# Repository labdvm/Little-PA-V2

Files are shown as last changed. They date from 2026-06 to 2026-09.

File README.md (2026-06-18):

# Little-PA-V2
Same as Little PA with few improvements

# Order from here:
- <a href="https://www.pcbway.com/project/shareproject/Little_PA_V2_SX1255_HAT_2c8ffceb.html">PCB from PCBWay</a>

# Changes to this version:
- Added island around TCXO and under to isolate heating from the cooper for better temperature stability.
- Added few bigger vias for better ventilation.
- Added Bandpass filter to the TX for better RF isolation.
- Added bridge in case if used without PA, you can jump with two 0R resistors to get signal directly from the SX1255.
- -----------------------------------------------------
# Work with PA:
- R29 and R32 not soldered.
# Work without the PA:
- U4 and C28 not soldered, R29 and R32 soldered.

# Z32IT

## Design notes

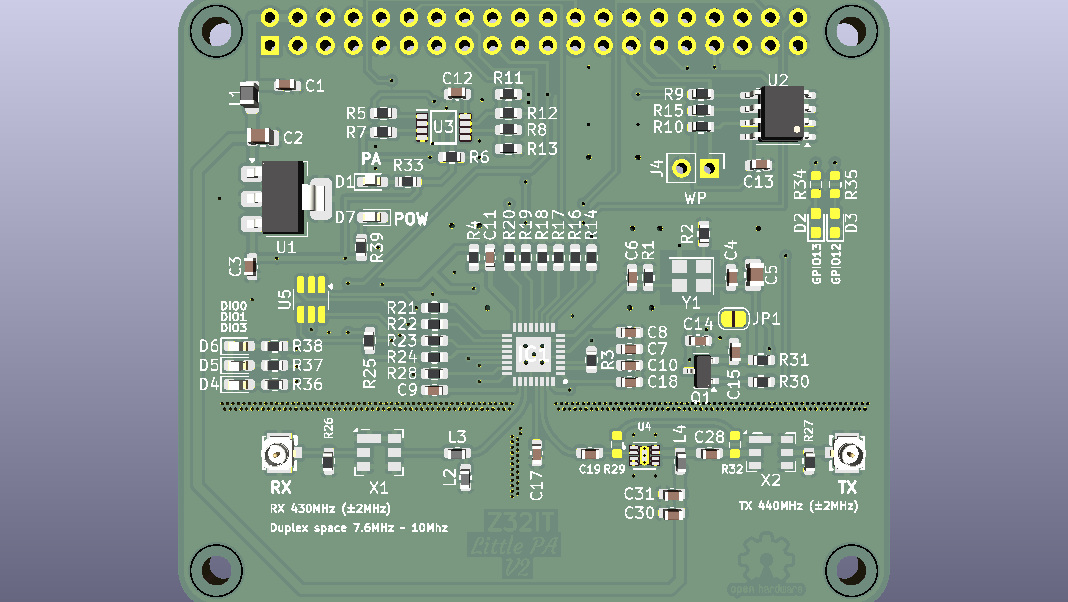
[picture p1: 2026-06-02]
Little PA V2.png

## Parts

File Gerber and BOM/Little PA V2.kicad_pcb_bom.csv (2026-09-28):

Designator | Quantity | Value | Footprint | Package | MPN | DNP | Mount_Type | Manufacturer | Manufacturer Product Number | KiLib_Generator | Description | Sim.Pin | Height | PN | PROD_ID | Part Number | MANUFACTURER_NAME | MF | MOUSER_PRICE-STOCK | DESCRIPTION | MOUSER_PART_NUMBER | Price | Check_prices | HEIGHT | SnapEDA_Link | MP | Description_1 | Availability | MANUFACTURER_PART_NUMBER | MAXIMUM_PACKAGE_HEIGHT | STANDARD | PARTREV | Purchase-URL | MANUFACTURER | Aliexpress | Model | TCXO-Footprints
C1, C10, C11, C15, C3, C30 | 6 | 1u | C_0603_1608Metric |  |  |  | smt | YAGEO | CC0603JRX7R6BB105
C12, C13, C14, C4, C7, C8, C9 | 7 | 100n | C_0603_1608Metric |  |  |  | smt | Vishay Vitramon | VJ0603Y104JXQPW1BC
C17, C19, C28, C31 | 4 | 100p | C_0603_1608Metric |  |  |  | smt | KEMET | C0603C101J8GACTU
C18 | 1 | 10n | C_0603_1608Metric |  |  |  | smt | KEMET | C0603C103K8RACTU
C2, C5 | 2 | 22u | C_0805_2012Metric |  | 1276-3148-1-ND |  | smt | Samsung Electro-Mechanics | CL31B226MPHNNNE | SMD_2terminal_chip_molded
C6 | 1 | 10p | C_0603_1608Metric |  |  |  | smt | KEMET | C0603C100J8GACTU
D1 | 1 | Red | LED_0603_1608Metric_Pad1.05x0.95mm_HandSolder |  | 160-1479-1-ND |  | smt | Lite-On Inc. | LTST-S270KRKT |  | Light emitting diode, small symbol | 1=K 2=A
D4, D5, D6 | 3 | Yellow | LED_0603_1608Metric_Pad1.05x0.95mm_HandSolder |  | 160-1437-1-ND |  | smt | Lite-On Inc. | LTST-C190KSKT |  | Light emitting diode, small symbol | 1=K 2=A
D7 | 1 | White | LED_0603_1608Metric_Pad1.05x0.95mm_HandSolder |  | 160-LTST-T180UWETCT-ND |  | smt | Lite-On Inc. | LTST-T180UWET |  | Light emitting diode, small symbol | 1=K 2=A
IC1 | 1 | SX1255 | QFN50P500X500X80-33N-D |  | SX1255IWLTRT |  | smt | Semtech Corporation | SX1255IWLTRT |  |  |  | 0.8 | 947-SX1255IWLTRT
J1, J2 | 2 | U.FL | U.FL |  | 343-CONMHF1-SMD-G-TCT-ND |  | smt | TE Connectivity Linx | CONMHF1-SMD-G-T |  |  |  |  |  | CONN-09193
L1 | 1 | 600 ohm/100MHz | L_0805_2012Metric |  | 490-1046-1-ND |  | smt | Murata Electronics | BLM21BD601SN1D |  | FERRITE BEAD 600 OHM 0805 1LN
L2 | 1 | 82n | L_0603_1608Metric |  |  |  | smt | Johanson Technology Inc. | LRC0603CJ82NGV001T
L3 | 1 | 39n | L_0603_1608Metric |  |  |  | smt | Johanson Technology Inc. | LRC0603CJ39NGV001T
L4 | 1 | 68nH | L_0603_1608Metric |  |  |  | smt | Johanson Technology Inc. | LRC0603CJ68NGV001T |  |  |  |  |  |  | 712-LRC0603CJ68NGV001TCT-ND
Q1 | 1 | BSS84 | SOT-23 |  | 3372-BSS84TR-ND |  | smt | MDD | BSS84
R1, R25 | 2 | 10K | R_0603_1608Metric |  |  |  | smt | Vishay Dale | CRCW060310K0FKEA
R10 | 1 | 1K | R_0603_1608Metric |  |  |  | smt | Vishay Dale | CRCW06031K00FKEA
R11, R13, R26, R27 | 4 | 1M | R_0603_1608Metric |  |  |  | smt | Vishay Dale | CRCW06031M00FKEA
R12, R17, R18, R19, R21, R23, R24, R30, R5, R6, R8 | 11 | 330R | R_0603_1608Metric |  |  |  | smt | Vishay Dale | CRCW0603330RFKEA
R14, R16, R20, R22, R28 | 5 | 33R | R_0603_1608Metric |  |  |  | smt | Vishay Dale | CRCW060333R0FKEA
R15, R38, R39, R9 | 4 | 3K3 | R_0603_1608Metric |  |  |  | smt | Vishay Dale | CRCW06033K30FKEA
R2, R7 | 2 | 0R | R_0603_1608Metric |  |  |  | smt | Vishay Dale | CRCW06030000Z0EA
R3, R31, R4 | 3 | 1R | R_0603_1608Metric |  |  |  | smt | Vishay Dale | CRCW06031R00FKEA
R33, R36, R37 | 3 | 1K5 | R_0603_1608Metric |  |  |  | smt | Vishay Dale | CRCW06031K50JNEA
U1 | 1 | MCP1703Ax-330xxDB | SOT-223-3_TabPin2 |  | MCP1703T-3302E/DBCT-ND |  | smt | Microchip Technology | MCP1703T-3302E/DB
U2 | 1 | 24LC256 | SOIC-8_3.9x4.9mm_P1.27mm |  | 24LC256-I/SN-ND |  | smt | Microchip Technology | 24LC256-I/SN
U3 | 1 | 74LVC1G74DP_125 | SOP65P400X110-8N | TSSOP8-8 Nexperia USA Inc. | 1727-5983-1-ND |  | smt | Nexperia USA Inc. | 74LVC1G74DP,125 |  |  |  |  |  |  |  | Nexperia | NXP USA Inc. | https://www.mouser.co.uk/ProductDetail/Nexperia/74LVC1G74DP125?qs=me8TqzrmIYWtKZiCsFqsMg%3D%3D | 74LVC1G74 - Single D-type flip-flop with set and reset; positive edge trigger@en-us | 771-LVC1GDP125 | None | https://www.snapeda.com/parts/74LVC1G74DP,125/NXP+Semiconductors/view-part/?ref=eda | 1.1mm | https://www.snapeda.com/parts/74LVC1G74DP,125/NXP+Semiconductors/view-part/?ref=snap | 74LVC1G74DP,125 | Flip Flop 1 Element D-Type 1 Bit Positive Edge 8-TSSOP, 8-MSOP (0.118, 3.00mm Width) | In Stock | 74LVC1G74DP,125
U4 | 1 | TQP3M9036 | SON50P200X200X95-9N | DFN-8 Qorvo | 2312-TQP3M9036CT-ND |  | smt | Qorvo | TQP3M9036 |  |  |  |  |  |  |  |  | Qorvo |  |  |  | None | https://www.snapeda.com/parts/TQP3M9036/Qorvo/view-part/?ref=eda |  | https://www.snapeda.com/parts/TQP3M9036/Qorvo/view-part/?ref=snap | TQP3M9036 | RF Amp Chip Single GP 2GHz 5.25V 8-Pin DFN EP T/R | In Stock |  | 0.95mm | IPC-7351B | N/A | https://www.snapeda.com/api/url_track_click_mouser/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 | Qorvo
X1 | 1 | TA0655A | Filter_SAW-6_3.8x3.8mm |  |  |  | smt |  |  |  | Bandpass Filter, 430MHz, BW-4MHz |  |  |  |  |  |  |  |  |  |  |  |  |  |  |  |  |  |  |  |  |  |  |  | https://www.aliexpress.com/item/1005011831789075.html?sourceType=1
X2 | 1 | TA2490A | Filter_SAW_Epcos_DCC6C_3x3mm |  |  |  | smt |  |  |  | Bandpass Filter, 440MHz, BW-2MHz |  |  |  |  |  |  |  |  |  |  |  |  |  |  |  |  |  |  |  |  |  |  |  | https://www.aliexpress.com/item/1005011831747244.html?sourceType=1
Y1 | 1 | 38.4MHz | Crystal_SMD_3225-4Pin_3.2x2.5mm |  | 114-TG2520SMN38.4000M-MCGNNM3CT-ND |  | smt | EPSON | TG2520SMN 38.4000M-MCGNNM3 |  | Clipped SW/0.5~1ppm |  |  |  |  |  |  |  |  |  |  |  |  |  |  |  |  |  |  |  |  |  |  |  |  | KDS-DSB321SDN or other brands | 3225 or 2510

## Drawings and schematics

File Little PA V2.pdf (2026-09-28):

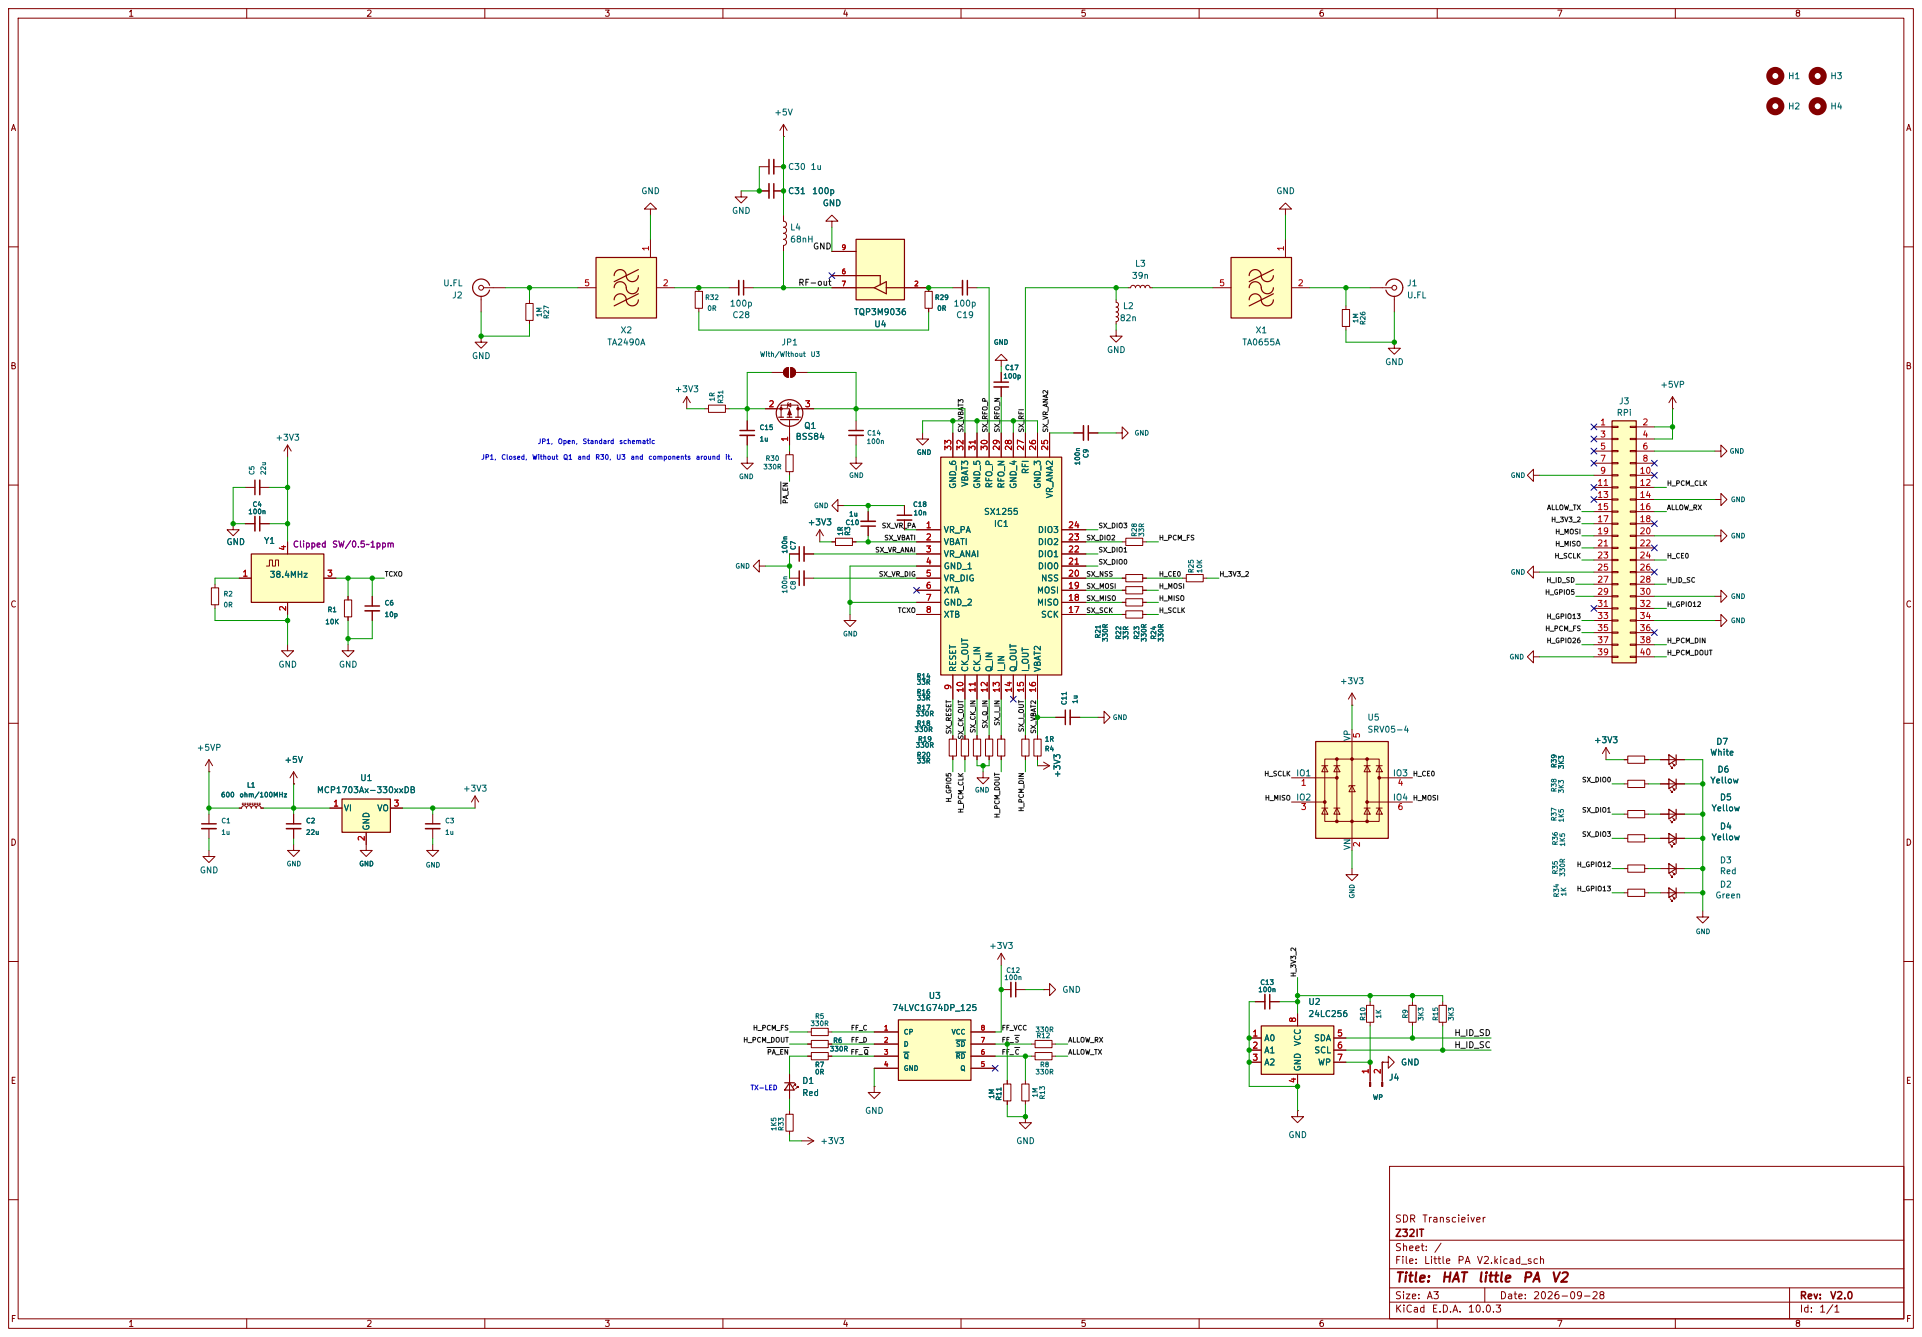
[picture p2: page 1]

JP1, Closed, Without Q1 and R30, U3 and components around it.

SDR Transcieiver
Sheet: /
File: Little PA V2.kicad_sch
Title: HAT little PA V2

Size: A3 | Rev: V2.0 | F Date: 2026-09-28
KiCad E.D.A. 10.0.3 | Id: 1/1

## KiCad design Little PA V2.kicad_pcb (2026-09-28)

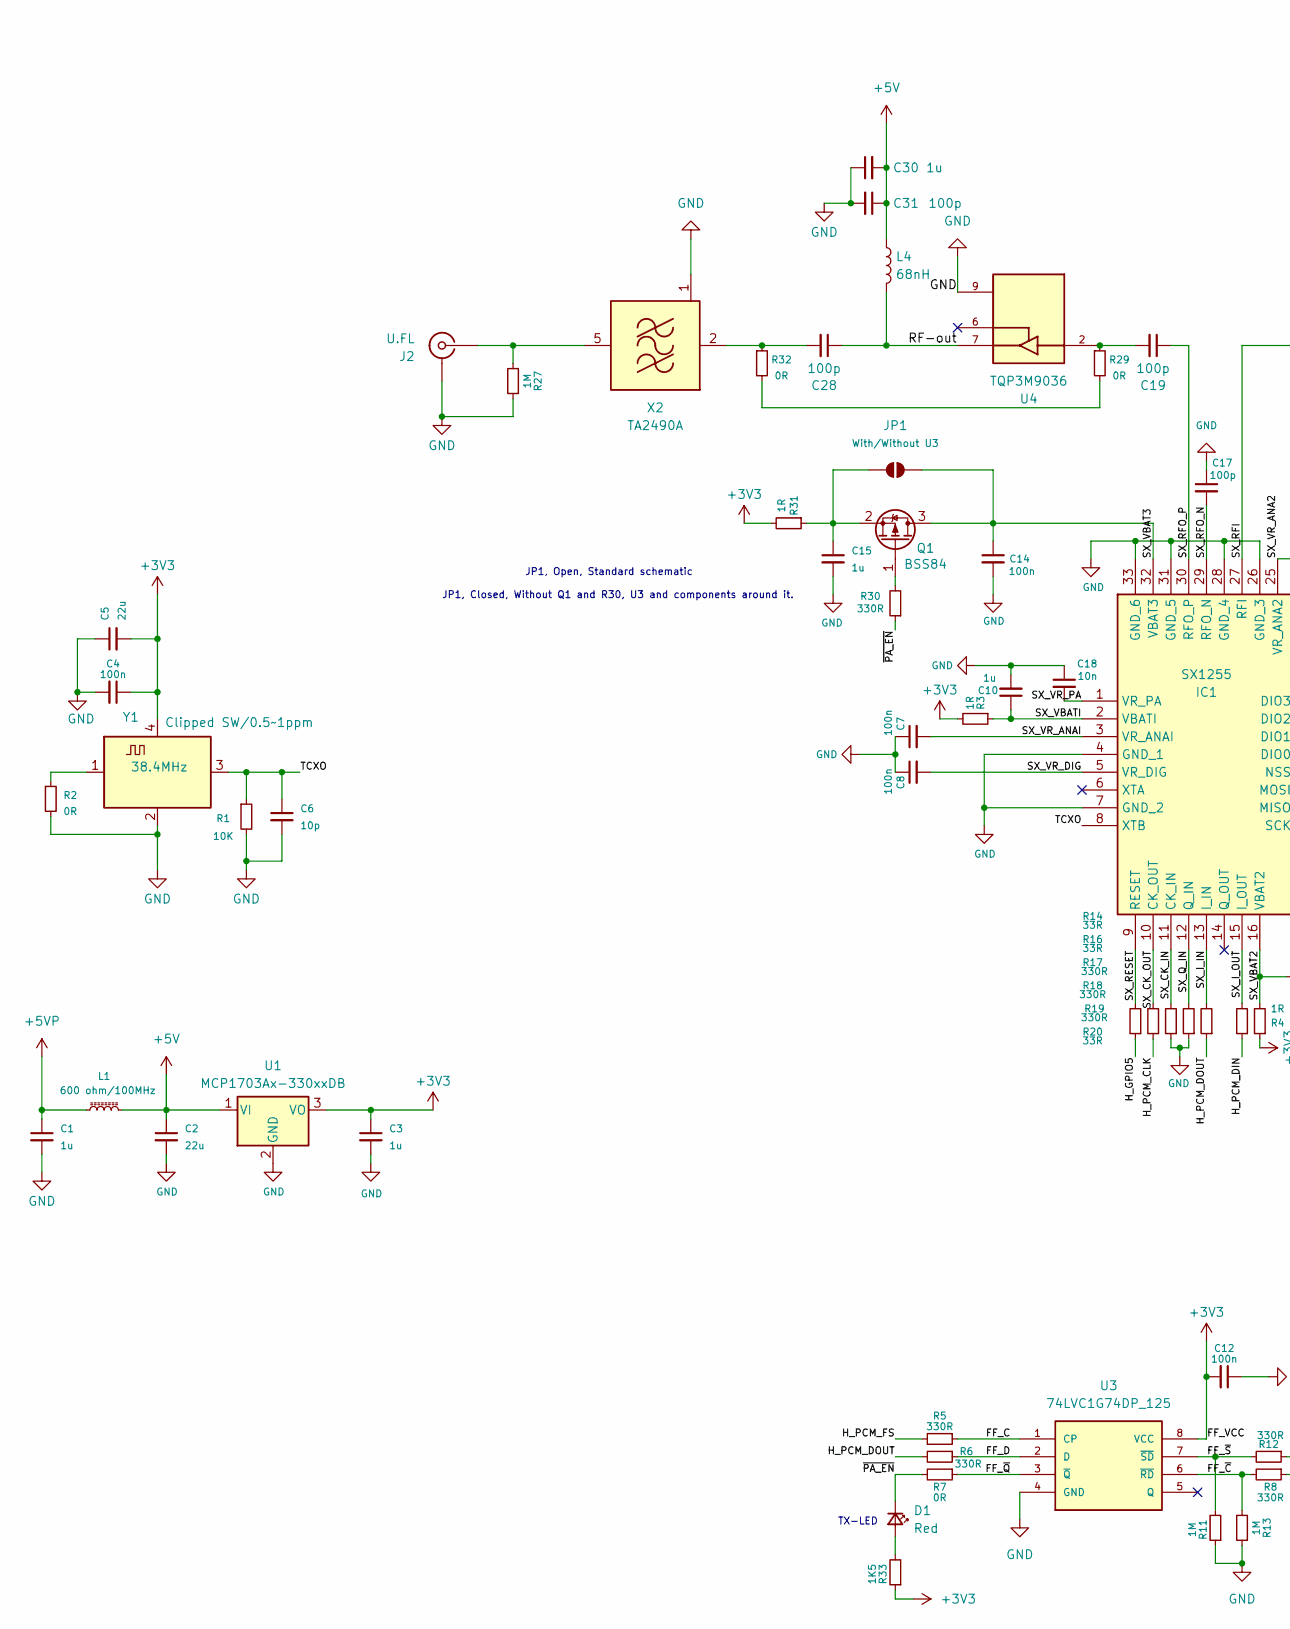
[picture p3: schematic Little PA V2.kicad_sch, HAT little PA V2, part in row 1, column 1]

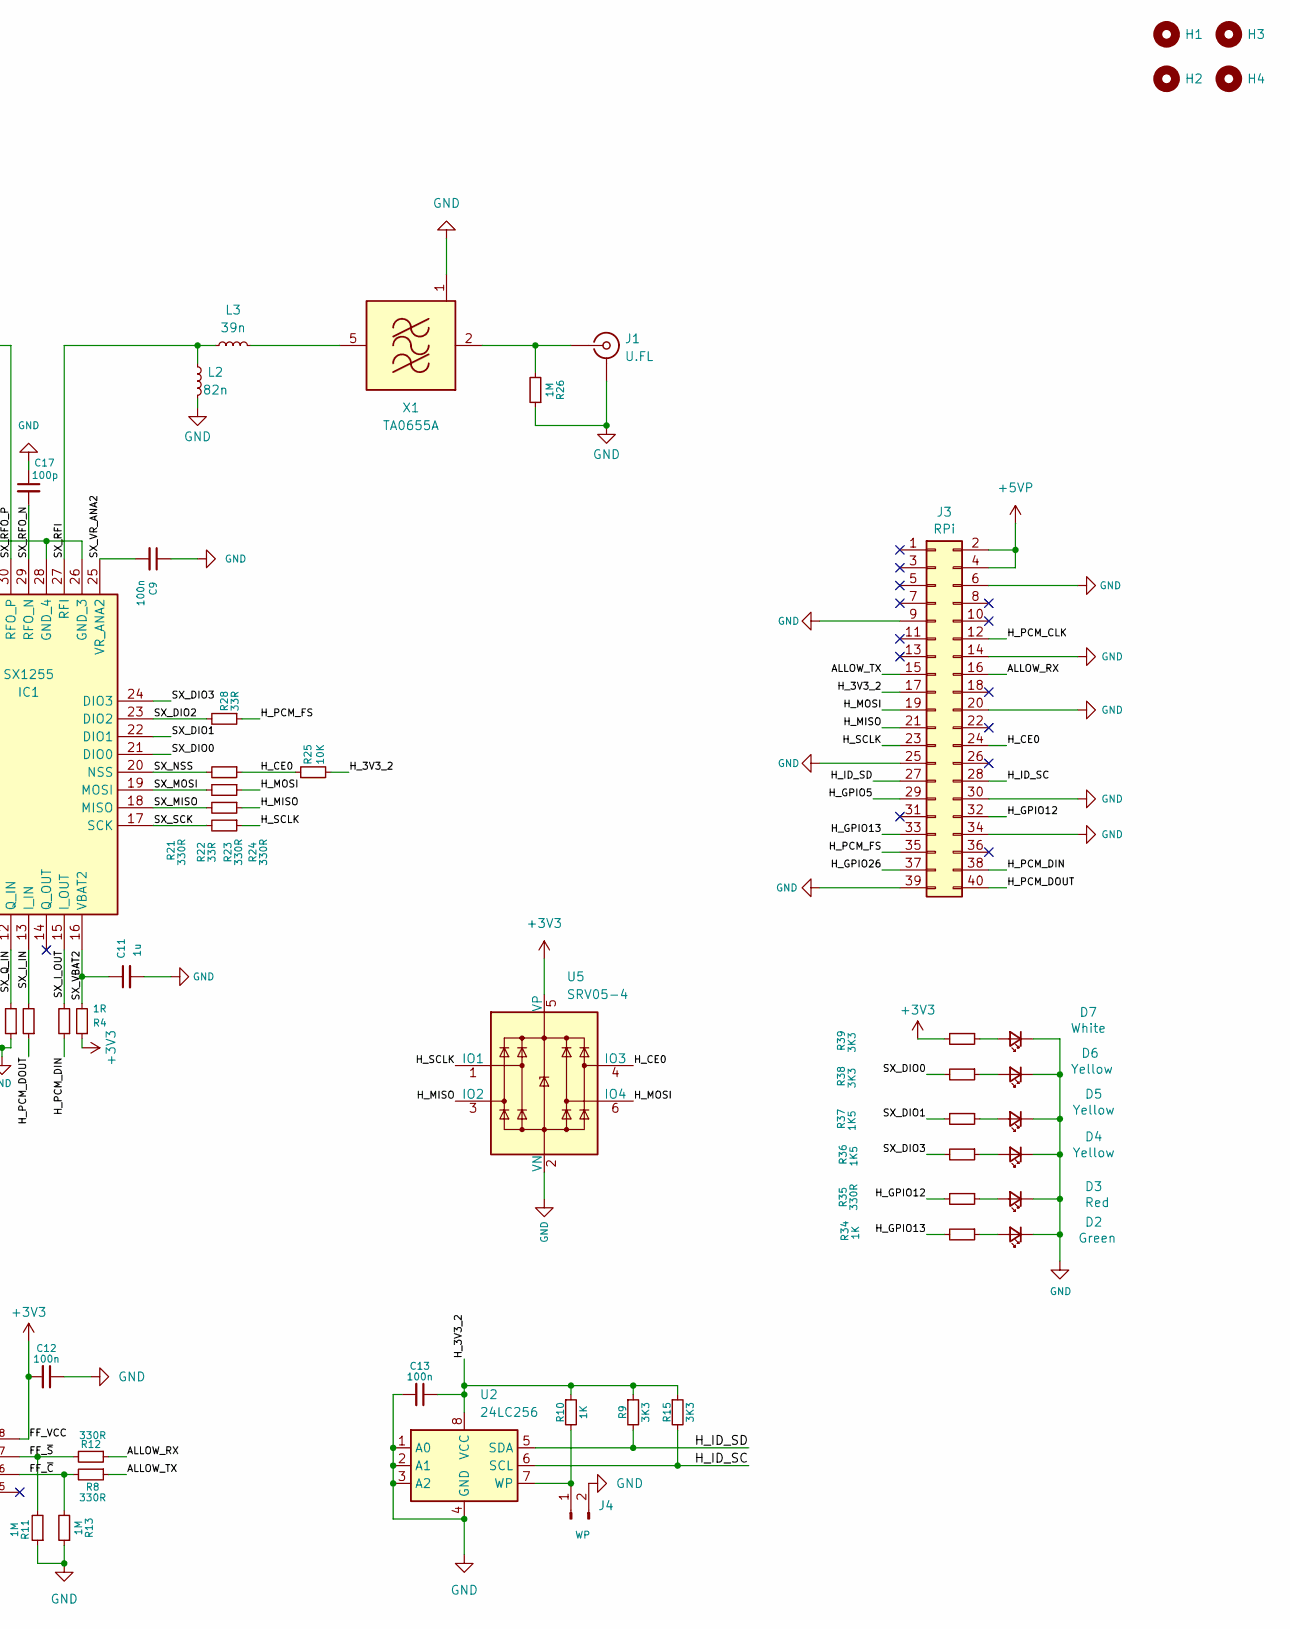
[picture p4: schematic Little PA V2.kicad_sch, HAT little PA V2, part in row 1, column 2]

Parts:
C1, C3, C10, C11, C15, C30: 1u; C_0603_1608Metric; Part Number 311-3484-1-ND
C2, C5: 22u; C_0805_2012Metric; Part Number 1276-3148-1-ND
C4, C7, C8, C9, C12, C13, C14: 100n; C_0603_1608Metric; Part Number 720-1688-1-ND
C6: 10p; C_0603_1608Metric; Part Number 399-14932-1-ND
C17, C19, C28, C31: 100p; C_0603_1608Metric; Part Number 399-15348-1-ND
C18: 10n; C_0603_1608Metric; Part Number 399-C0603C103K8RACTUCT-ND
D1, D3: Red; LED_0603_1608Metric_Pad1.05x0.95mm_HandSolder; Part Number 160-1479-1-ND
D2: Green; LED_0603_1608Metric_Pad1.05x0.95mm_HandSolder; Part Number 754-APT1608SGD3CT-ND
D4, D5, D6: Yellow; LED_0603_1608Metric_Pad1.05x0.95mm_HandSolder; Part Number 160-1437-1-ND
D7: White; LED_0603_1608Metric_Pad1.05x0.95mm_HandSolder; Part Number 160-LTST-T180UWETCT-ND
H1, H2, H3, H4: MountingHole; MountingHole_2.7mm_M2.5_DIN965
IC1: SX1255; QFN50P500X500X80-33N-D; Part Number SX1255IWLTRTCT-ND
J1, J2: U.FL; Part Number 343-CONMHF1-SMD-G-TCT-ND
J3: RPi; PinSocket_2x20_P2.54mm_Vertical
J4: WP; PinHeader_1x02_P2.54mm_Vertical
JP1: With/Without U3; SolderJumper-2_P1.3mm_Open_RoundedPad1.0x1.5mm
L1: 600 ohm/100MHz; L_0805_2012Metric; Part Number 490-1046-1-ND
L2: 82n; L_0603_1608Metric; Part Number 712-LRC0603CJ82NGV001TCT-ND
L3: 39n; L_0603_1608Metric; Part Number 712-LRC0603CJ39NGV001TCT-ND
L4: 68nH; L_0603_1608Metric; Part Number 712-LRC0603CJ68NGV001TCT-ND
Q1: BSS84; SOT-23; Part Number 3372-BSS84TR-ND
R1, R25: 10K; R_0603_1608Metric; Part Number 541-10.0KHCT-ND
R2, R7, R29, R32: 0R; R_0603_1608Metric; Part Number 541-0.0GCT-ND
R3, R4, R31: 1R; R_0603_1608Metric; Part Number 541-1.00HHCT-ND
R5, R6, R8, R12, R17, R18, R19, R21, R23, R24, R30, R35: 330R; R_0603_1608Metric; Part Number 541-330HCT-ND
R9, R15, R38, R39: 3K3; R_0603_1608Metric; Part Number 541-3.30KHCT-ND
R10, R34: 1K; R_0603_1608Metric; Part Number 541-1.00KHCT-ND
R11, R13, R26, R27: 1M; R_0603_1608Metric; Part Number 541-1.00MHCT-ND
R14, R16, R20, R22, R28: 33R; R_0603_1608Metric; Part Number 541-33.0HCT-ND
R33, R36, R37: 1K5; R_0603_1608Metric; Part Number 541-1.5KGCT-ND
U1: MCP1703Ax-330xxDB; SOT-223-3_TabPin2; Part Number MCP1703T-3302E/DBCT-ND
U2: 24LC256; SOIC-8_3.9x4.9mm_P1.27mm; Part Number 24LC256-I/SN-ND
U3: 74LVC1G74DP_125; SOP65P400X110-8N; Part Number 1727-5983-1-ND
U4: TQP3M9036; SON50P200X200X95-9N; Part Number 2312-TQP3M9036CT-ND
U5: SRV05-4; SOT-23-6_Handsoldering; DigiKey Part Number SRV05-4CT-ND
X1: TA0655A; Filter_SAW-6_3.8x3.8mm
X2: TA2490A; Filter_SAW_Epcos_DCC6C_3x3mm
Y1: 38.4MHz; Crystal_SMD_3225-4Pin_3.2x2.5mm; Part Number 114-TG2520SMN38.4000M-MCGNNM3CT-ND

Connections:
+3V3: C3.1, C4.1, C5.2, C12.2, R3.2, R4.1, R31.2, R33.1, R39.2, U1.3 (VO), U3.8 (VCC), U5.5 (VP), Y1.4 (VDD)
+5V: C2.1, C30.2, C31.1, L1.2, L4.1, U1.1 (VI)
+5VP: C1.1, J3.2, J3.4, L1.1
/ALLOW_RX: J3.16, R12.1
/ALLOW_TX: J3.15, R8.1
/FF_C: R5.1, U3.1 (CP)
/FF_D: R6.1, U3.2 (D)
/FF_~C: R8.2, R13.2, U3.6 (~RD)
/FF_~Q: R7.1, U3.3 (~Q)
/FF_~S: R11.2, R12.2, U3.7 (~SD)
/H_3V3_2: C13.1, J3.17, R9.1, R10.1, R15.1, R25.2, U2.8 (VCC)
/H_CE0: J3.24, R24.1, R25.1, U5.4 (IO3)
/H_GPIO5: J3.29, R14.1
/H_GPIO12: J3.32, R35.2
/H_GPIO13: J3.33, R34.2
/H_GPIO26: J3.37
/H_ID_SC: J3.28, R15.2, U2.6 (SCL)
/H_ID_SD: J3.27, R9.2, U2.5 (SDA)
/H_MISO: J3.21, R22.1, U5.3 (IO2)
/H_MOSI: J3.19, R23.1, U5.6 (IO4)
/H_PCM_CLK: J3.12, R16.1
/H_PCM_DIN: J3.38, R20.1
/H_PCM_DOUT: J3.40, R6.2, R19.1
/H_PCM_FS: J3.35, R5.2, R28.1
/H_SCLK: J3.23, R21.1, U5.1 (IO1)
/RF-out: C28.1, L4.2, U4.7
/SX_CK_IN: IC1.11 (CK_IN), R17.2
/SX_CK_OUT: IC1.10 (CK_OUT), R16.2
/SX_DIO0: IC1.21 (DIO0), R38.2
/SX_DIO1: IC1.22 (DIO1), R37.2
/SX_DIO2: IC1.23 (DIO2), R28.2
/SX_DIO3: IC1.24 (DIO3), R36.2
/SX_I_IN: IC1.13 (I_IN), R19.2
/SX_I_OUT: IC1.15 (I_OUT), R20.2
/SX_MISO: IC1.18 (MISO), R22.2
/SX_MOSI: IC1.19 (MOSI), R23.2
/SX_NSS: IC1.20 (NSS), R24.2
/SX_Q_IN: IC1.12 (Q_IN), R18.2
/SX_RESET: IC1.9 (RESET), R14.2
/SX_RFI: IC1.27 (RFI), L2.2, L3.2
/SX_RFO_N: C17.2, IC1.29 (RFO_N)
/SX_RFO_P: C19.1, IC1.30 (RFO_P)
/SX_SCK: IC1.17 (SCK), R21.2
/SX_VBAT2: C11.1, IC1.16 (VBAT2), R4.2
/SX_VBAT3: C14.1, IC1.32 (VBAT3), JP1.2 (B), Q1.3 (D)
/SX_VBATI: C10.1, IC1.2 (VBATI), R3.1
/SX_VR_ANA2: C9.2, IC1.25 (VR_ANA2)
/SX_VR_ANAI: C7.2, IC1.3 (VR_ANAI)
/SX_VR_DIG: C8.2, IC1.5 (VR_DIG)
/SX_VR_PA: C18.2, IC1.1 (VR_PA)
/TCXO: C6.1, IC1.8 (XTB), R1.1, Y1.3 (OUT)
/~PA_EN: D1.1 (K), R7.2, R30.1
GND: C1.2, C2.2, C3.2, C4.2, C5.1, C6.2, C7.1, C8.1, C9.1, C10.2, C11.2, C12.1, C13.2, C14.2, C15.2, C17.1, C18.1, C30.1, C31.2, D2.1 (K), D3.1 (K), D4.1 (K), D5.1 (K), D6.1 (K), D7.1 (K), IC1.4 (GND_1), IC1.7 (GND_2), IC1.26 (GND_3), IC1.28 (GND_4), IC1.31 (GND_5), IC1.33 (GND_6), J1.2 (Ext), J2.2 (Ext), J3.6, J3.9, J3.14, J3.20, J3.25, J3.30, J3.34, J3.39, J4.2, L2.1, R1.2, R2.2, R11.1, R13.1, R17.1, R18.1, R26.1, R27.1, U1.2 (GND), U2.1 (A0), U2.2 (A1), U2.3 (A2), U2.4 (GND), U3.4 (GND), U4.9, U4.V1, U4.V2, U4.V3, U5.2 (VN), X1.1 (GND), X1.3 (GND), X1.4 (GND), X1.6 (GND), X2.1 (GND), X2.3 (GND), X2.4 (GND), X2.6 (GND), Y1.2 (GND)
unnamed: C19.2, R29.1, U4.2
unnamed: D1.2 (A), R33.2
unnamed: D2.2 (A), R34.1
unnamed: D3.2 (A), R35.1
unnamed: D4.2 (A), R36.1
unnamed: D5.2 (A), R37.1
unnamed: D6.2 (A), R38.1
unnamed: D7.2 (A), R39.1
unnamed: J1.1 (In), R26.2, X1.2 (IN)
unnamed: J2.1 (In), R27.2, X2.5 (OUT)
unnamed: J4.1, R10.2, U2.7 (WP)
unnamed: C15.1, JP1.1 (A), Q1.2 (S), R31.1
unnamed: Q1.1 (G), R30.2
unnamed: R29.2, R32.2
unnamed: L3.1, X1.5 (OUT)
unnamed: C28.2, R32.1, X2.2 (IN)
unnamed: R2.1, Y1.1 (Tri-State)

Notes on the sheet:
JP1, Closed, Without Q1 and R30, U3 and components around it.
JP1, Open, Standard schematic
TX-LED

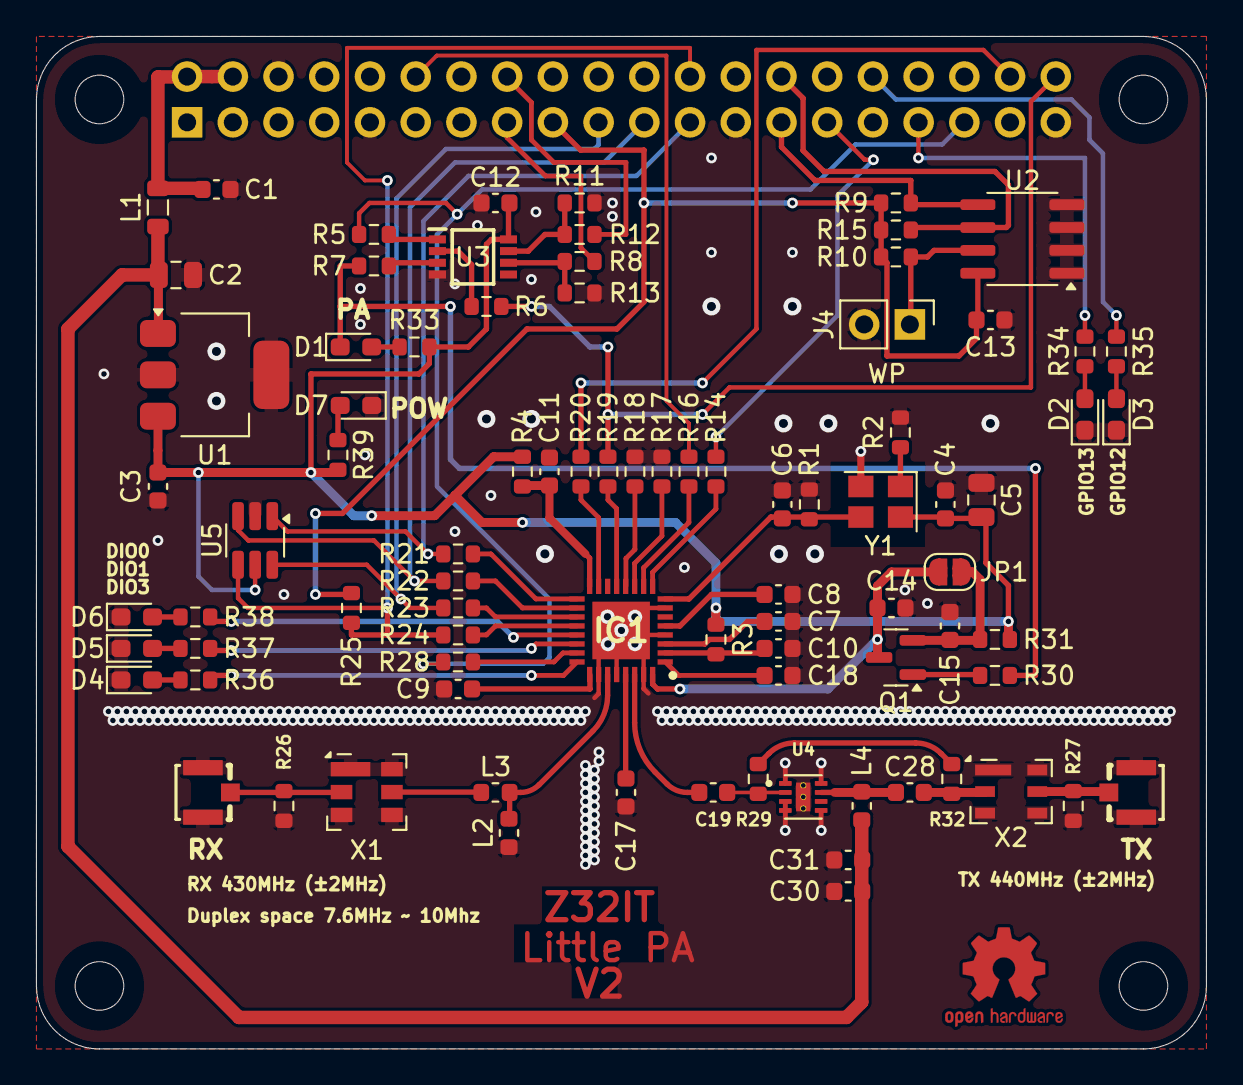
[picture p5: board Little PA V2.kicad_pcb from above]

Board: 2 copper layers, 65.0 x 56.2 mm, 90 parts (1 on the bottom side), 69 nets.
